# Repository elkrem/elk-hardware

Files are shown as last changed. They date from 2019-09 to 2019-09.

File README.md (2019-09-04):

# Elk Board Schematics and Board files #

## Overview ##

This repository contains the schematics and board files for [Elk](https://www.kickstarter.com/projects/233173198/elk-the-dev-board-for-the-decentralized-world) board.

## Status ##

The Elk board project has been [cancelled](https://www.kickstarter.com/projects/233173198/elk-the-dev-board-for-the-decentralized-world/posts/2613884), thus the repo is unmaintained and provided for reference only in the hope it will useful.

There board in the [Kickstarter Video](https://www.kickstarter.com/projects/233173198/elk-the-dev-board-for-the-decentralized-world) is available in this [tag](https://github.com/elkrem/elk-hardware/releases/tag/v1). Other commits has been added after that.

## License and Copyright ##



These files are free; you can redistribute them and/or modify them under the terms of the Creative Commons Attribution-ShareAlike 4.0 International License only, as published by the Creative Commons organization.

These files are distributed in the hope that they will be useful, but WITHOUT ANY WARRANTY; without even the implied warranty of MERCHANTABILITY or FITNESS FOR A PARTICULAR PURPOSE.  See the Creative Commons Attribution-ShareAlike 4.0 International License for more details (a copy is included in the LICENSE file that accompanied these files).

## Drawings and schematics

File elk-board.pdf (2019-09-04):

# MCU Voltage Regulator 3.3V /1A

# USB Connector

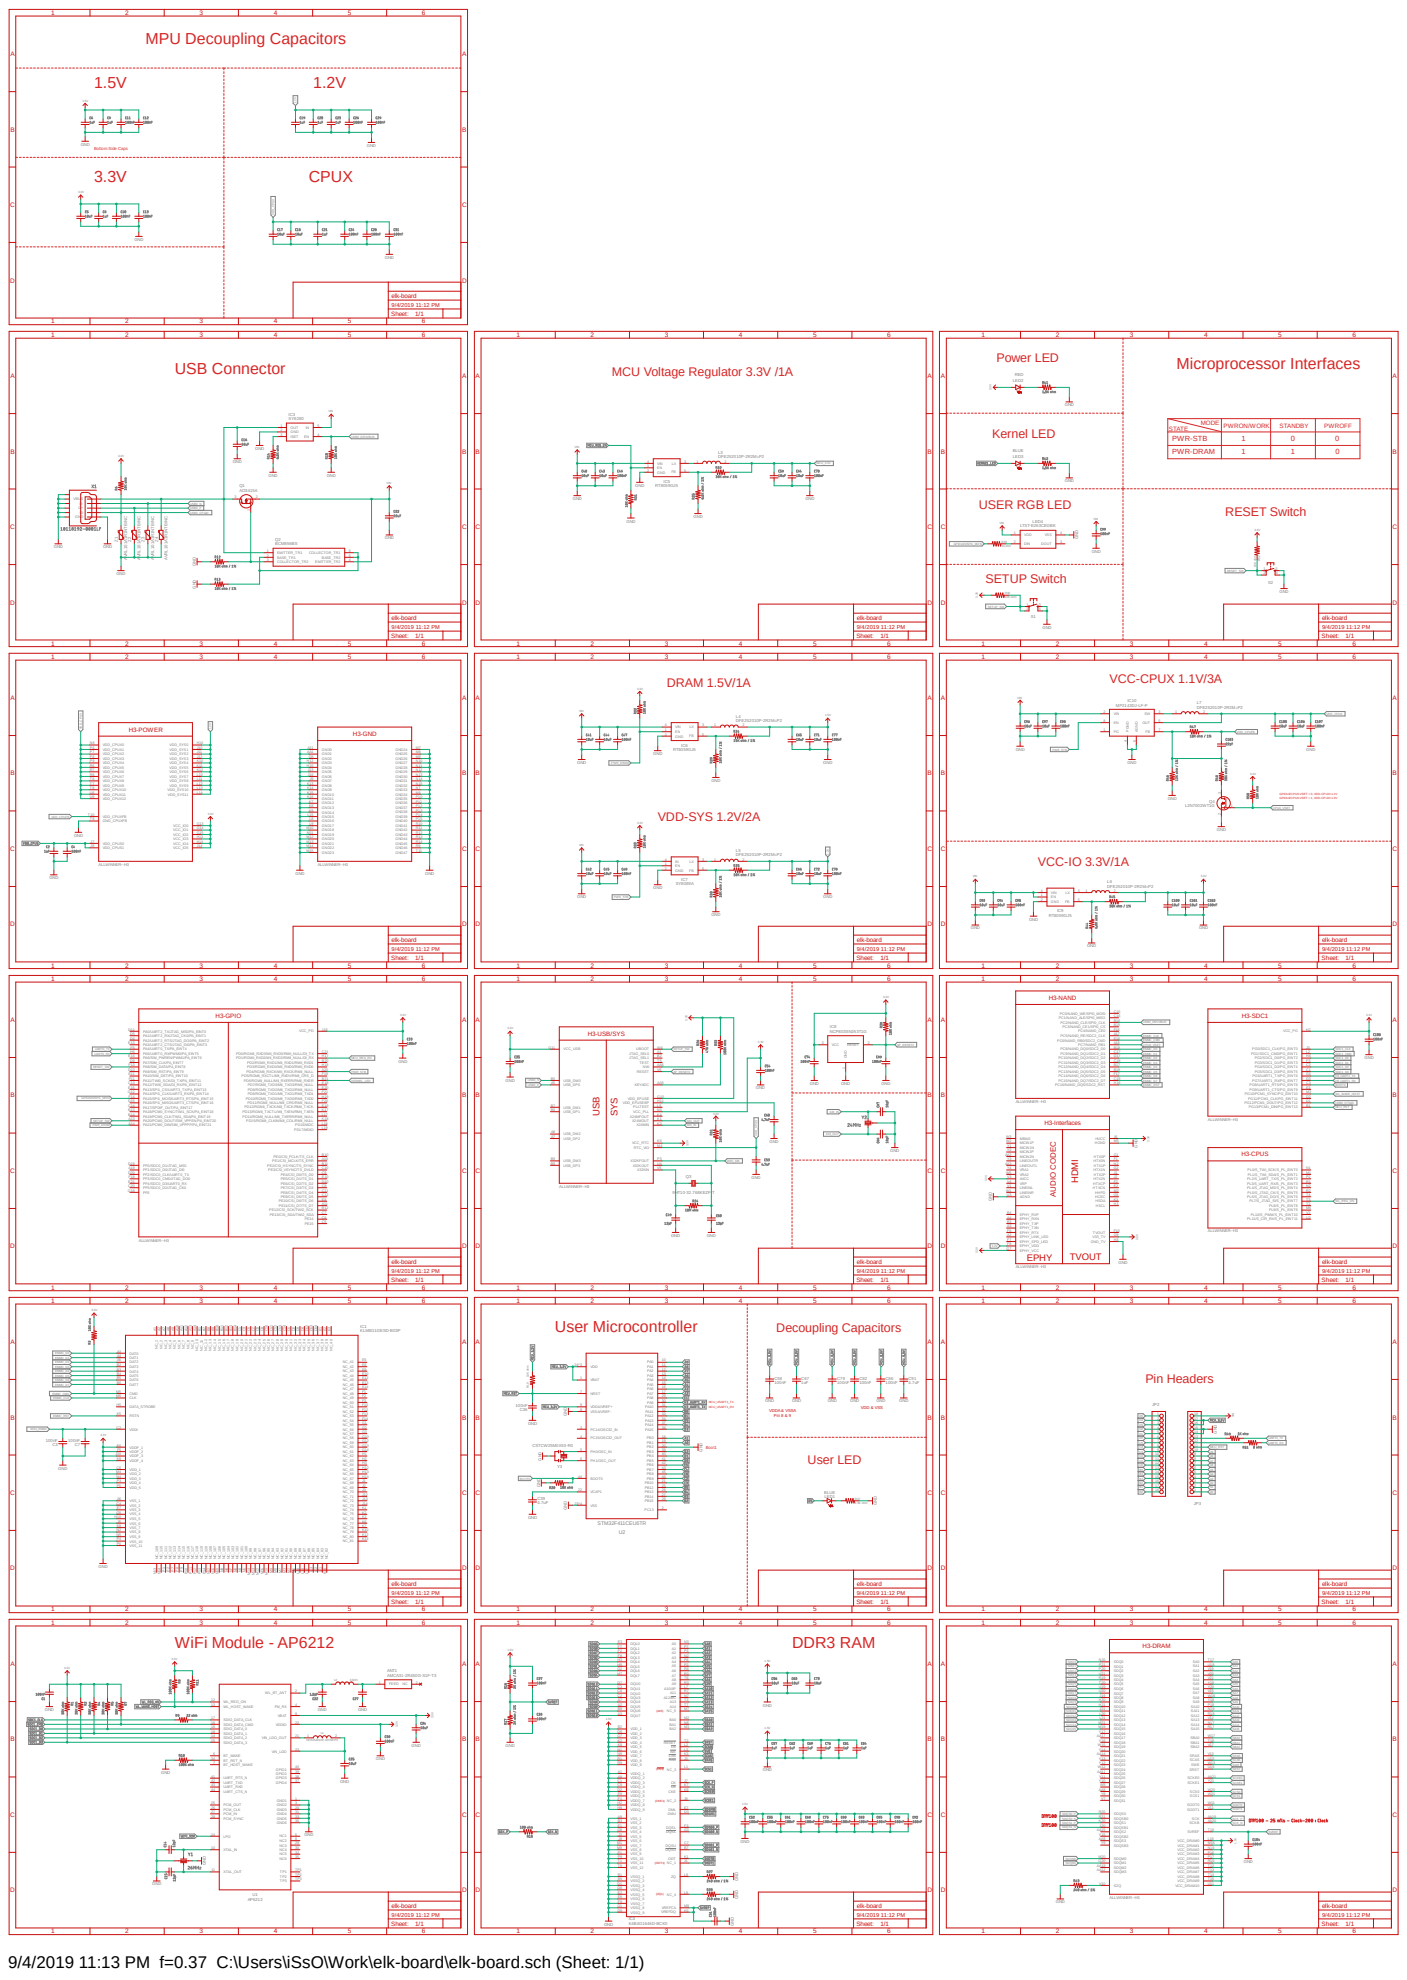
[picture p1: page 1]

MODE | PWRON/WORK | STANDBY | PWROFF 1

PWR-STB | | 0 0
PWR-DRAM | 1 1 | | 0

GPIOL6/CPUX-VSET = 0, VDD-CPUX=1.1V
GPIOL6/CPUX-VSET = 1, VDD-CPUX=1.3V

H3-USB/SYS USB SYS

9/4/2019 11:13 PM f=0.37 C:\Users\iSsO\Work\elk-board\elk-board.sch (Sheet: 1/1)

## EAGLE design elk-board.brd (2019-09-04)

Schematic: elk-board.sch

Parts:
ANT1: AMCA31-2R450G-S1F-T3; ANTC3216X140N
C1, C3, C4, C7, C10, C11, C12, C13, C24, C26, C28, C29, C30, C31, C33, C35, C36, C37, C38, C46, C47, C48, C51, C52, C54, C55, C58, C61, C68, C70, C74, C75, C77, C78, C79, C80, C82, C83, C85, C86, C89, C90, C92, C95, C98, C99, C102, C104, C107, C108: 100nF; 0402
C2, C6, C8, C9, C19, C20, C21, C23, C57, C62, C67, C69, C76, C81, C84: 1uF; 0402
C5, C16, C25, C34, C40, C41, C42, C43, C44, C45, C56, C59, C63, C64, C65, C66, C71, C72, C73, C93, C94, C96, C97, C100, C101: 10uF; 0603
C14, C15, C49, C50: 12pF; 0402
C17, C18, C105, C106: 10uF; TOLBA_0603
C22: 1.5pF; 0402
C27: CAPACITOR-(INCH)-0402; 0402
C32: 22uF; 0603
C39, C53, C60, C91: 4.7uF; 0402
C87, C88: 18pF; 0402
C103: 22pF; 0402
IC1: KLM8G1GESD-B03P; BGA153C50P14X14_1150X1300X80
IC2: ALLWINNER--H3; BGA347C65P21X21_1400X1400X118
IC3: SY6280; SOT95P285X140-5N
IC4: K4B4G1646D-BCK0; BGA96C80P9X16_1000X1330X120
IC5, IC6, IC9: RT8059GJ5; SOT94P280X100-5N
IC7: SY8089A; SOT95P285X140-5N
IC8: NCP803SN263T1G; SOT96P237X111-3N
IC10: MP2143DJ-LF-P; SOT65P280X100-8N
JP2, JP3: PINHD-1X18_2.54-S; 1X18-S
L1: DFE252010P-4R7M=P2; INDC2520X100N
L2: 3.9nH; RESC0402_L
L3, L4, L5, L6, L7: DFE252010P-2R2M=P2; INDC2520X100N
LED1, LED3: BLUE; 0603-LED
LED2: RED; 0603-LED
LED4: LTST-E263CEGBK
Q1: AO3415A; SOT95P280X125-3N
Q2: BCM856BS; SOT65P210X110-6N
Q3: 9HT10-32.768KEZF-T; 3.2X1.5
Q4: L2N7002WT1G; SOT65P220X100-3N
R1, R2, R4, R5, R7: 30K ohm; 0402
R3, R6, R15, R19, R20, R21, R22, R23, R31, R38, R40, R50, R52: 10K ohm; 0402
R8, R10, R11, R33: 100K ohm; 0402
R9: 22 ohm; 0402
R12, R13, R29, R30, R35, R47: 10K ohm / 1%; 0402
R14: 6.8K ohm; 0402
R16, R17: 2K ohm / 1%; 0402
R18: 100 ohm; 0402
R24: 10M ohm; 0402
R25, R44: 6.8K ohm / 1%; 0402
R26: 47K ohm; 0402
R27, R28, R43: 240 ohm / 1%; 0402
R32, R45, R48: 30K ohm / 1%; 0402
R34: 15K ohm / 1%; 0402
R37, R41, R42: 1.5K ohm; 0402
R39: 33 ohm; 0402
R46: 12K ohm / 1%; 0402
R49: 1K ohm; 0402
R51: 0 ohm; 0402
S1, S2: KMR231GLFS; TACTILE_SWITCH_SMD
U1: AP6212
U2: STM32F411CEU6TR; UFQFPN-48
X1: 10118192-0001LF; 10118192-0001LF(MICRO-USB-B-AMPHENOL-FCI)
Y1: 26MHz; 4-SMD-2X1.6MM
Y2: 24MHz; CRYSTAL-SMD-3.2X2.5MM-EPSON-TSX-3225
Y3: CSTCW25M0X53-R0
Z1, Z2, Z3, Z4: AVRL101A1R1NTB/NC; 0402-RES

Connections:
1.2V: C19.1, C20.1, C23.1, C26.1, C29.1, C66.1, C72.1, C78.1, IC2.F8 (EPHY_VDD), IC2.H10 (VDD_SYS0), IC2.J10 (VDD_SYS1), IC2.J11 (VDD_SYS2), IC2.J12 (VDD_SYS3), IC2.K10 (VDD_SYS4), IC2.K11 (VDD_SYS5), IC2.K12 (VDD_SYS6), IC2.L10 (VDD_SYS7), IC2.L11 (VDD_SYS8), IC2.L12 (VDD_SYS9), IC2.L13 (VDD_SYS10), IC2.L14 (VDD_SYS11), L5.2, R35.2
1.5V: C6.1, C9.1, C11.1, C12.1, C37.1, C52.1, C55.1, C56.1, C57.1, C61.1, C62.1, C63.1, C65.1, C68.1, C69.1, C71.1, C73.1, C75.1, C76.1, C77.1, C80.1, C81.1, C83.1, C84.1, C85.1, C90.1, C92.1, IC2.L16 (VCC_DRAM0), IC2.M16 (VCC_DRAM1), IC2.N16 (VCC_DRAM2), IC2.P16 (VCC_DRAM3), IC2.P17 (VCC_DRAM4), IC2.R16 (VCC_DRAM5), IC2.T12 (VCC_DRAM6), IC2.T13 (VCC_DRAM7), IC2.T14 (VCC_DRAM8), IC2.T15 (VCC_DRAM9), IC2.U11 (VCC_DRAM10), IC4.A1 (VDDQ_1), IC4.A8 (VDDQ_2), IC4.B2 (VDD_1), IC4.C1 (VDDQ_3), IC4.C9 (VDDQ_4), IC4.D2 (VDDQ_5), IC4.D9 (VDD_2), IC4.E9 (VDDQ_6), IC4.F1 (VDDQ_7), IC4.G7 (VDD_3), IC4.H2 (VDDQ_8), IC4.H9 (VDDQ_9), IC4.K2 (VDD_4), IC4.K8 (VDD_5), IC4.N1 (VDD_6), IC4.N9 (VDD_7), IC4.R1 (VDD_8), IC4.R9 (VDD_9), L4.2, R16.2, R34.2
3.3V: C1.2, C5.1, C8.1, C10.1, C13.1, C30.1, C33.1, C34.1, C35.1, C54.1, C74.1, C100.1, C101.1, C102.1, C108.1, IC1.C6 (VDD_1), IC1.E6 (VDDF_1), IC1.F5 (VDDF_2), IC1.J10 (VDDF_3), IC1.K9 (VDDF_4), IC1.M4 (VDD_2), IC1.N4 (VDD_3), IC1.P3 (VDD_4), IC1.P5 (VDD_5), IC2.G7 (EPHY_VCC), IC2.G9 (V33_TV), IC2.G10 (VDD_EFUSE), IC2.G11 (VCC_USB), IC2.G13 (VCC_IO0), IC2.G14 (VCC_IO1), IC2.G15 (VCC_IO2), IC2.H7 (VCC_PG), IC2.H13 (VCC_IO3), IC2.H14 (VCC_IO4), IC2.J6 (HVCC), IC2.J14 (VCC_IO5), IC2.J15 (VCC_PD), IC2.K6 (VCC_RTC), IC2.N3 (VCC_PLL), IC2.V3 (AVCC), IC8.3 (VCC), L6.2, LED2.A, R1.1, R2.1, R3.2, R4.1, R5.1, R6.2, R7.1, R8.1, R11.1, R22.2, R23.2, R26.1, R31.1, R33.1, R38.1, R40.1, R45.2, R50.2, R52.1, U1.9 (VBAT), U1.22 (VDDIO)
A0: JP3.1, U2.19 (PB1)
A1: JP3.2, U2.18 (PB0)
A2: JP3.3, U2.17 (PA7)
A3: JP3.4, U2.16 (PA6)
A4: JP3.5, U2.15 (PA5)
A5: JP3.6, U2.14 (PA4)
A6: JP3.7, U2.13 (PA3)
A7: JP3.8, U2.12 (PA2)
A8: JP3.9, U2.11 (PA1)
A9: JP3.10, U2.10 (PA0)
AP_RESET#: C89.1, IC2.V6 (RESET), IC8.2 (!RESET), R38.2
B0: JP2.18, U2.32 (PA11)
B1: JP2.17, U2.33 (PA12)
B2: JP2.16, U2.28 (PB15)
B3: JP2.15, U2.27 (PB14)
B4: JP2.14, U2.26 (PB13)
B5: JP2.13, U2.25 (PB12)
BOOT0: IC2.C3 (PG8/UART1_RTS/PG_EINT8), R20.1, U2.44 (BOOT0)
C0: JP2.12, U2.45 (PB8)
C1: JP2.11, U2.29 (PA8)
C2: JP2.10, U2.46 (PB9)
C3: JP2.9, U2.21 (PB10)
C4: JP2.8, U2.43 (PB7)
C5: JP2.7, U2.42 (PB6)
CPUX_VSET: IC2.A16 (PC7/NAND_RB1), Q4.1 (G), R50.1
D0: JP2.6, U2.41 (PB5)
D1: JP2.5, U2.40 (PB4)
D2: JP2.4, U2.39 (PB3)
D3: JP2.3, U2.38 (PA15)
D4: JP2.2, U2.37 (PA14)
D5: JP2.1, LED1.A, U2.34 (PA13)
EMMC_CLK: IC1.M6 (CLK), IC2.A17 (PC5/NAND_RE/SDC2_CLK)
EMMC_CMD: IC1.M5 (CMD), IC2.E16 (PC6/NAND_RB0/SDC2_CMD), R3.1
EMMC_D0: IC1.A3 (DAT0), IC2.B18 (PC8/NAND_DQ0/SDC2_D0)
EMMC_D1: IC1.A4 (DAT1), IC2.C17 (PC9/NAND_DQ1/SDC2_D1)
EMMC_D2: IC1.A5 (DAT2), IC2.D17 (PC10/NAND_DQ2/SDC2_D2)
EMMC_D3: IC1.B2 (DAT3), IC2.C18 (PC11/NAND_DQ3/SDC2_D3)
EMMC_D4: IC1.B3 (DAT4), IC2.B17 (PC12/NAND_DQ4/SDC2_D4)
EMMC_D5: IC1.B4 (DAT5), IC2.B19 (PC13/NAND_DQ5/SDC2_D5)
EMMC_D6: IC1.B5 (DAT6), IC2.F17 (PC14/NAND_DQ6/SDC2_D6)
EMMC_D7: IC1.B6 (DAT7), IC2.C19 (PC15/NAND_DQ7/SDC2_D7)
EMMC_RST: IC1.K5 (RSTN), IC2.H16 (PC16/NAND_DQS/SDC2_RST)
GND: C1.1, C2.2, C3.1, C4.2, C5.2, C6.2, C7.1, C8.2, C9.2, C10.2, C11.2, C12.2, C13.2, C14.1, C15.1, C16.2, C17.2, C18.2, C19.2, C20.2, C21.2, C22.1, C23.2, C24.2, C25.2, C26.2, C27.1, C28.2, C29.2, C30.2, C31.2, C32.2, C33.2, C34.2, C35.2, C36.1, C38.2, C39.2, C40.2, C41.2, C42.2, C43.2, C44.2, C45.2, C46.2, C47.2, C48.2, C49.2, C50.2, C51.2, C52.2, C53.2, C54.2, C55.2, C56.2, C57.2, C58.2, C59.2, C60.2, C61.2, C62.2, C63.2, C64.2, C65.2, C66.2, C67.2, C68.2, C69.2, C70.2, C71.2, C72.2, C73.2, C74.2, C75.2, C76.2, C77.2, C78.2, C79.2, C80.2, C81.2, C82.2, C83.2, C84.2, C85.2, C86.2, C87.1, C88.1, C89.2, C90.2, C91.2, C92.2, C93.2, C94.2, C95.2, C96.2, C97.2, C98.2, C99.2, C100.2, C101.2, C102.2, C104.2, C105.2, C106.2, C107.2, C108.2, IC1.A6 (VSS_1), IC1.C4 (VSS_2), IC1.E7 (VSS_3), IC1.G5 (VSS_4), IC1.H10 (VSS_5), IC1.J5 (VSS_6), IC1.K8 (VSS_7), IC1.N2 (VSS_8), IC1.N5 (VSS_9), IC1.P4 (VSS_10), IC1.P6 (VSS_11), IC2.A21 (GND0), IC2.AA1 (GND1), IC2.G8 (GND2), IC2.H8 (GND_TV), IC2.H12 (GND3), IC2.H15 (GND4), IC2.J9 (GND7), IC2.J13 (GND5), IC2.J16 (GND6), IC2.K7 (GND12), IC2.K8 (GND13), IC2.K9 (GND14), IC2.K13 (GND8), IC2.K14 (GND9), IC2.K15 (GND10), IC2.K16 (GND11), IC2.L8 (GND16), IC2.L9 (GND17), IC2.L15 (GND15), IC2.M5 (HGND), IC2.M7 (GND24), IC2.M8 (GND25), IC2.M9 (GND26), IC2.M10 (GND18), IC2.M11 (GND19), IC2.M12 (GND20), IC2.M13 (GND21), IC2.M14 (GND22), IC2.M15 (GND23), IC2.N7 (GND33), IC2.N9 (GND34), IC2.N10 (GND27), IC2.N11 (GND28), IC2.N12 (GND29), IC2.N13 (GND30), IC2.N14 (GND31), IC2.N15 (GND32), IC2.P10 (GND35), IC2.P11 (GND36), IC2.P12 (GND37), IC2.P13 (GND38), IC2.P14 (GND39), IC2.P15 (GND40), IC2.R9 (GND46), IC2.R10 (GND41), IC2.R11 (GND42), IC2.R12 (GND43), IC2.R13 (GND44), IC2.R14 (GND45), IC2.T9 (GND_CPUXFB), IC2.T11 (GND47), IC2.U3 (AGND), IC3.2 (GND), IC4.A9 (VSS_1), IC4.B1 (VSSQ_1), IC4.B3 (VSS_2), IC4.B9 (VSSQ_2), IC4.D1 (VSSQ_3), IC4.D8 (VSSQ_4), IC4.E1 (VSS_3), IC4.E2 (VSSQ_5), IC4.E8 (VSSQ_6), IC4.F9 (VSSQ_7), IC4.G1 (VSSQ_8), IC4.G8 (VSS_4), IC4.G9 (VSSQ_9), IC4.J2 (VSS_5), IC4.J8 (VSS_6), IC4.M1 (VSS_7), IC4.M9 (VSS_8), IC4.P1 (VSS_9), IC4.P9 (VSS_10), IC4.T1 (VSS_11), IC4.T9 (VSS_12), IC5.2 (GND), IC6.2 (GND), IC7.2 (GND), IC8.1 (GND), IC9.2 (GND), IC10.4 (PGND), IC10.6 (AGND), JP3.14, JP3.15, LED4.4 (VSS), Q4.2 (S), R10.1, R12.1, R13.1, R14.1, R15.1, R17.1, R20.2, R21.2, R25.1, R27.2, R28.2, R29.1, R30.1, R37.2, R41.2, R42.2, R43.1, R44.1, R46.1, S1.3, S1.4, S2.3, S2.4, U1.1 (GND1), U1.3 (GND2), U1.20 (GND3), U1.31 (GND4), U1.33 (GND5), U1.36 (GND6), U2.8 (VSSA/VREF-), U2.20 (PB2), U2.23 (VSS), U2.35 (VSS), U2.47 (VSS), U2.49 (VSS), X1.CGND1 (SGND1), X1.CGND2 (SGND2), X1.CGND3 (SGND3), X1.CGND4 (SGND4), X1.CGND5 (SGND5), X1.CGND6 (SGND6), X1.GND, Y1.2, Y1.4, Y2.2 (3), Y2.4 (3), Y3.GND, Z1.1, Z2.1, Z3.1, Z4.1
GPIOA15/SPI1_MOSI: IC2.F14 (PA15/SPI1_MOSI/UART3_RTS/PA_EINT15), R39.1
H3_UART1_RX: IC2.D3 (PG7/UART1_RX/PG_EINT7), U2.30 (PA9)
H3_UART1_TX: IC2.G4 (PG6/UART1_TX/PG_EINT6), U2.31 (PA10)
KERNEL_LED: IC2.B21 (PD6/RGMII_NULL/MII_RXERR/RMII_RXER), LED3.A
MCU_3.3V: C58.1, C59.1, C64.1, C67.1, C70.1, C79.1, C82.1, C86.1, C91.1, JP3.16, JP3.17, L3.2, R19.1, R32.2, U2.1 (VBAT), U2.9 (VDDA/VREF+), U2.24 (VDD), U2.36 (VDD), U2.48 (VDD)
MCU_REG_EN: IC2.H17 (PD1/RGMII_RXD2/MII_RXD2/RMII_NULL/DI_RX), IC5.1 (EN), R21.1
MCU_RST: C36.2, IC2.B1 (PG13/PCM1_DIN/PG_EINT13), JP3.11, R19.2, U2.7 (NRST)
unnamed: R9.1, U1.17 (SDIO_DATA_CLK)
unnamed: JP3.12, R51.2
unnamed: IC5.3 (LX), L3.1
unnamed: LED1.K, R37.1
unnamed: LED3.K, R42.1
unnamed: IC6.3 (LX), L4.1
unnamed: R10.2, U1.34 (BT_RST_N)
unnamed: IC5.5 (FB), R25.2, R32.1
unnamed: C15.2, U1.11 (XTAL_OUT), Y1.1
unnamed: C14.2, U1.10 (XTAL_IN), Y1.3
unnamed: JP3.13, R49.2
unnamed: ANT1.1 (FEED), C27.2, L2.2
unnamed: LED4.2 (DIN), R39.2
unnamed: C25.1, L1.2, U1.23 (VIN_LDO)
unnamed: U2.5 (PH0/OSC_IN), Y3.IN
unnamed: U2.6 (PH1/OSC_OUT), Y3.OUT
unnamed: L1.1, U1.21 (VIN_LDO_OUT)
unnamed: IC6.5 (FB), R29.2, R34.1
unnamed: IC7.3 (LX), L5.1
unnamed: C22.2, L2.1, U1.2 (WL_BT_ANT)
unnamed: LED2.K, R41.1
unnamed: C39.1, U2.22 (VCAP1)
unnamed: IC4.L8 (ZQ), R27.1
unnamed: C16.1, IC3.1 (OUT), Q1.3 (D), Q2.1 (EMITTER_TR1), X1.VBUS, Z4.2
unnamed: IC7.5 (FB), R30.2, R35.1
unnamed: C49.1, IC2.V5 (X32KIN), Q3.1, R24.2
unnamed: IC10.3 (SW), L7.1
unnamed: C103.2, IC10.7 (FB), R46.2, R47.1, R48.2
unnamed: IC3.3 (ISET), R14.2
unnamed: IC9.3 (LX), L6.1
unnamed: IC2.V10 (SZQ), R43.2
unnamed: IC9.5 (FB), R44.2, R45.1
unnamed: Q4.3 (D), R48.1
unnamed: Q1.1 (G), Q2.3 (COLLECTOR_TR2), R12.2
unnamed: Q2.2 (BASE_TR1), Q2.5 (BASE_TR2), Q2.6 (COLLECTOR_TR1), R13.2
unnamed: C50.1, IC2.U4 (X32KOUT), Q3.2, R24.1
unnamed: C60.1, IC2.H11 (VDD_EFUSEBP)
unnamed: IC2.AA6 (NMI), R26.2
unnamed: IC2.AA5 (KEYADC), R33.2
unnamed: IC4.L9 (NC_4), R28.1
PWR_DRAM: IC2.A14 (PA21/PCM0_DIN/SIM_VPPPP/PA_EINT21), IC6.1 (EN), R22.1
PWR_STB: IC2.A20 (PD4/RGMII_RXCK/MII_RXCK/RMII_NULL), IC7.1 (EN), IC10.8 (EN), R23.1
RESET_SW: IC2.F13 (PA8/SIM_DATA/PA_EINT8), R52.2, S2.1, S2.2
SA0: IC2.T17 (SA0), IC4.N3 (A0)
SA1: IC2.U18 (SA1), IC4.P7 (A1)
SA2: IC2.V19 (SA2), IC4.P3 (A2)
SA3: IC2.V20 (SA3), IC4.N2 (A3)
SA4: IC2.V21 (SA4), IC4.P8 (A4)
SA5: IC2.Y19 (SA5), IC4.P2 (A5)
SA6: IC2.Y20 (SA6), IC4.R8 (A6)
SA7: IC2.V15 (SA7), IC4.R2 (A7)
SA8: IC2.W18 (SA8), IC4.T8 (A8)
SA9: IC2.Y18 (SA9), IC4.R3 (A9)
SA10: IC2.P19 (SA10), IC4.L7 (A10/AP)
SA11: IC2.N19 (SA11), IC4.R7 (A11)
SA12: IC2.R18 (SA12), IC4.N7 (A12/!BC)
SA13: IC2.V12 (SA13), IC4.T3 (A13)
SA14: IC2.N17 (SA14), IC4.T7 (A14)
SA15: IC2.R17 (SA15), IC4.M7 (NC_5)
SBA0: IC2.W17 (SBA0), IC4.M2 (BA0)
SBA1: IC2.T18 (SBA1), IC4.N8 (BA1)
SBA2: IC2.V17 (SBA2), IC4.M3 (BA2)
SCAS: IC2.U15 (SCAS), IC4.K3 (!CAS)
SCKE0: IC2.AA21 (SCKE0), IC4.K9 (CKE)
SCKE1: IC2.Y21 (SCKE1), IC4.J9 (NC_2)
SCK_N: IC2.AA20 (SCKB), IC4.K7 (!CK), R18.1
SCK_P: IC2.AA19 (SCK), IC4.J7 (CK), R18.2
SCS0: IC2.W20 (SCS0), IC4.L2 (!CS)
SCS1: IC2.W21 (SCS1), IC4.L1 (NC_3)
SDC1_CLK: IC2.J3 (PG0/SDC1_CLK/PG_EINT0), R9.2
SDC1_CMD: IC2.L2 (PG1/SDC1_CMD/PG_EINT1), R7.2, U1.16 (SDIO_DATA_CMD)
SDC1_D0: IC2.H4 (PG2/SDC1_D0/PG_EINT2), R5.2, U1.18 (SDIO_DATA_0)
SDC1_D1: IC2.F3 (PG3/SDC1_D1/PG_EINT3), R4.2, U1.19 (SDIO_DATA_1)
SDC1_D2: IC2.C2 (PG4/SDC1_D2/PG_EINT4), R2.2, U1.14 (SDIO_DATA_2)
SDC1_D3: IC2.C1 (PG5/SDC1_D3/PG_EINT5), R1.2, U1.15 (SDIO_DATA_3)
SDQ0: IC2.N20 (SDQ0), IC4.F7 (DQL1)
SDQ1: IC2.P21 (SDQ1), IC4.H8 (DQL5)
SDQ2: IC2.P20 (SDQ2), IC4.F8 (DQL3)
SDQ3: IC2.U21 (SDQ3), IC4.H3 (DQL4)
SDQ4: IC2.R19 (SDQ4), IC4.H7 (DQL7)
SDQ5: IC2.T20 (SDQ5), IC4.E3 (DQL0)
SDQ6: IC2.U19 (SDQ6), IC4.G2 (DQL6)
SDQ7: IC2.U20 (SDQ7), IC4.F2 (DQL2)
SDQ8: IC2.J19 (SDQ8), IC4.A7 (DQU4)
SDQ9: IC2.H20 (SDQ9), IC4.A2 (DQU5)
SDQ10: IC2.H21 (SDQ10), IC4.A3 (DQU7)
SDQ11: IC2.J21 (SDQ11), IC4.B8 (DQU6)
SDQ12: IC2.L20 (SDQ12), IC4.C8 (DQU2)
SDQ13: IC2.L21 (SDQ13), IC4.D7 (DQU0)
SDQ14: IC2.M21 (SDQ14), IC4.C3 (DQU1)
SDQ15: IC2.M19 (SDQ15), IC4.C2 (DQU3)
SDQM0: IC2.M20 (SDQM0), IC4.E7 (DML)
SDQM1: IC2.G20 (SDQM1), IC4.D3 (DMU)
SDQS0_N: IC2.R21 (SDQSB0), IC4.G3 (!DQSL)
SDQS0_P: IC2.R20 (SDQS0), IC4.F3 (DQSL)
SDQS1_N: IC2.J20 (SDQSB1), IC4.B7 (!DQSU)
SDQS1_P: IC2.K20 (SDQS1), IC4.C7 (DQSU)
SETUP_SW: IC2.A13 (PA20/PCM0_DOUT/SIM_VPPEN/PA_EINT20), IC2.W6 (UBOOT), R40.2, S1.1, S1.2
SODT0: IC2.W11 (SODT0), IC4.K1 (ODT)
SODT1: IC2.V11 (SODT1), IC4.J1 (NC_1)
SRAS: IC2.V13 (SRAS), IC4.J3 (!RAS)
SRST: IC2.U16 (SRST), IC4.T2 (!RESET)
SVREF: C37.2, C38.1, C51.1, C104.1, IC2.T16 (SVREF), IC4.H1 (VREFDQ), IC4.M8 (VREFCA), R16.1, R17.2
SWE: IC2.W13 (SWE), IC4.L3 (!WE)
UART0_RX: IC2.H6 (PA5/UART0_RX/PWM0/PA_EINT5), R51.1
UART0_TX: IC2.F5 (PA4/UART0_TX/PA_EINT4), R49.1
USB0_DRVVBUS: IC2.B16 (PC2/NAND_CLE/SPI0_CLK), IC3.4 (EN), R15.2
USB0_N: IC2.B5 (USB_DM0), X1.D-, Z3.2
USB0_OTGID: IC2.D1 (PG12/PCM1_DOUT/PG_EINT12), R6.1, X1.ID, Z1.2
USB0_P: IC2.A5 (USB_DP0), X1.D+, Z2.2
VDDI_EMMC: C3.2, C7.2, IC1.C2 (VDDI)
VDD_CPUFB: C103.1, IC2.T10 (VDD_CPUXFB), R47.2
VDD_CPUS: C2.1, C4.1, C53.1, IC2.J7 (VDD_CPUS0), IC2.J8 (VDD_CPUS1), IC2.M4 (RTC_VIO)
VDD_CPUX: C17.1, C18.1, C21.1, C24.1, C28.1, C31.1, C105.1, C106.1, C107.1, IC2.N8 (VDD_CPUX0), IC2.P6 (VDD_CPUX1), IC2.P7 (VDD_CPUX2), IC2.P8 (VDD_CPUX3), IC2.P9 (VDD_CPUX4), IC2.R6 (VDD_CPUX5), IC2.R7 (VDD_CPUX6), IC2.R8 (VDD_CPUX7), IC2.T6 (VDD_CPUX8), IC2.T7 (VDD_CPUX9), IC2.T8 (VDD_CPUX10), IC2.U6 (VDD_CPUX11), IC2.U9 (VDD_CPUX12), IC10.5 (OUT), L7.2
VIN: C32.1, C40.1, C41.1, C42.1, C43.1, C44.1, C45.1, C46.1, C47.1, C48.1, C93.1, C94.1, C95.1, C96.1, C97.1, C98.1, C99.1, IC3.5 (IN), IC5.4 (VIN), IC6.4 (VIN), IC7.4 (IN), IC9.1 (EN), IC9.4 (VIN), IC10.2 (VIN), JP3.18, LED4.1 (VDD), Q1.2 (S), Q2.4 (EMITTER_TR2)
WIFI_32K: IC2.P3 (X32KFOUT), R31.2, U1.24 (LPO)
WL_REG_ON: IC2.T3 (PL7/S_JTAG_SI/S_PL_EINT7), R11.2, U1.12 (WL_REG_ON)
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

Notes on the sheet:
WiFi Module - AP6212
DDR3 RAM
MCU Voltage Regulator 3.3V /1A
Decoupling Capacitors
VDDA & VSSA Pin 8 & 9
VDD & VSS
User LED
User Microcontroller
Pin Headers
USB Connector
DRAM 1.5V/1A
VDD-SYS 1.2V/2A
VCC-CPUX 1.1V/3A
VCC-IO 3.3V/1A
Microprocessor Interfaces
MCU_USART1_TX
MCU_USART1_RX
USER RGB LED
SETUP Switch
Kernel LED
Power LED
PWR-STB
PWR-DRAM
PWRON/WORK
STANDBY
PWROFF
MODE
STATE
RESET Switch
Boot1
MPU Decoupling Capacitors
GPIOL6/CPUX-VSET = 0, VDD-CPUX=1.1V GPIOL6/CPUX-VSET = 1, VDD-CPUX=1.3V
Bottom Side Caps
Diff100
Diff100 - 25 mils - Clock-200 : Clock
CPUX
3.3V
1.2V
1.5V

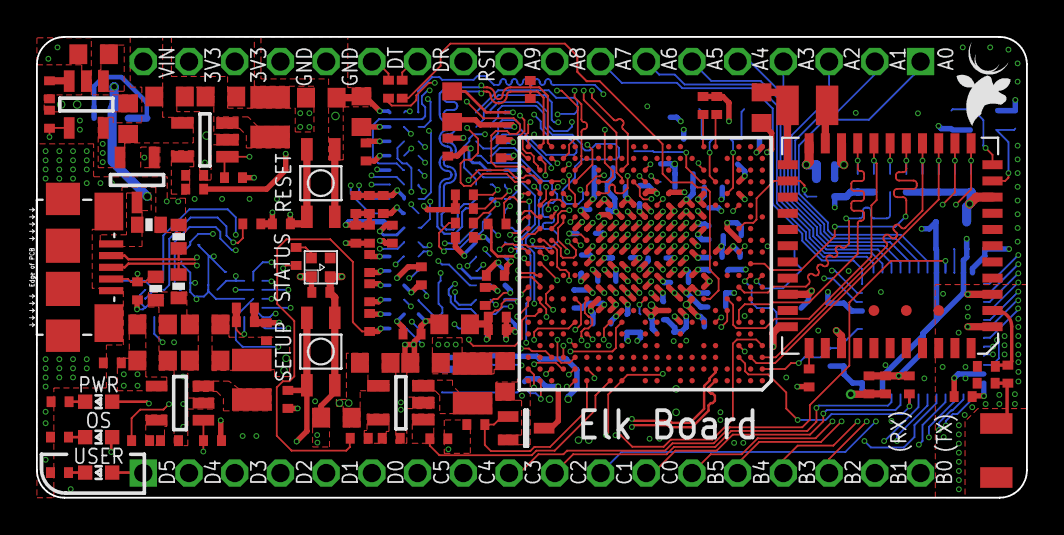
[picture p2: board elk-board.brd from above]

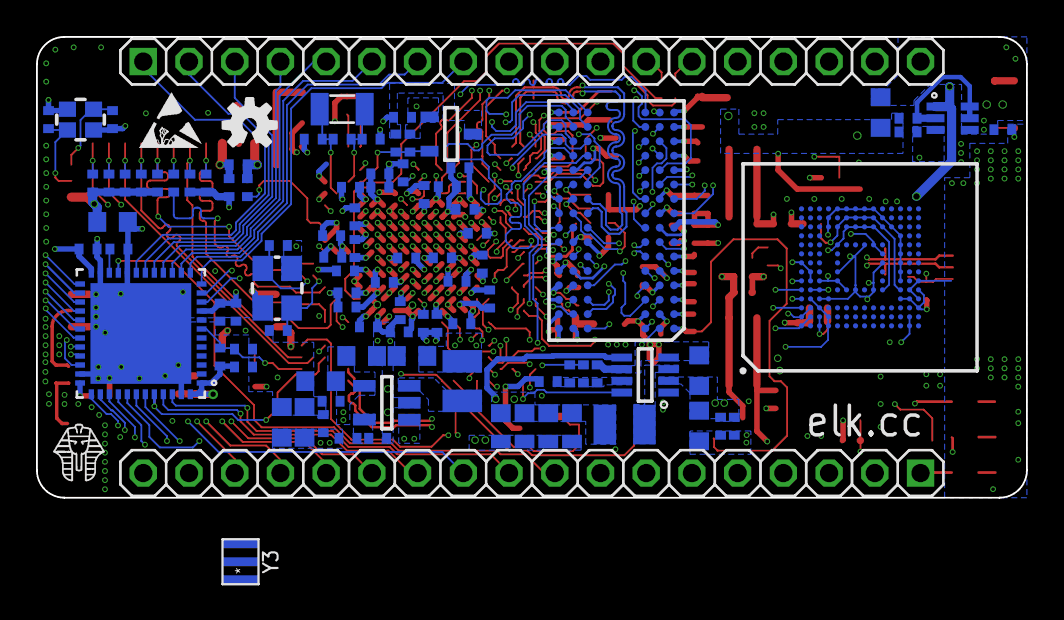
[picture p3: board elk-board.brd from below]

Board: 8 copper layers, 55.0 x 25.6 mm, 200 parts (98 on the bottom side), 173 nets.

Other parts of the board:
U$1: OSHW-LOGO-S

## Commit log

2019-07-08 Initial commit
    1st iteration (H3) sent to China on June, 12th, 2019
    [elk-board.brd, elk-board.sch]
2019-09-04 Added pdf schematics
2019-09-04 Added emmc chip and integrated antenna
    [elk-board.brd, elk-board.sch]
2019-09-04 Finished emmc and antenna (WIP)
    [elk-board.brd, elk-board.sch]
2019-09-04 Finished eMMC Data Lines legth matching (CMD is not included)
    [elk-board.brd, elk-board.sch]
2019-09-04 Modified the GND & PWR Planes around the Antenna
    [elk-board.brd]
2019-09-04 Moved the Antenna a little bit
    [elk-board.brd]
2019-09-04 Added and Modified GND vias and increased eMMC CLK length and it's clearance with nearby traces
    [elk-board.brd]
2019-09-04 Added Some GND vias and moved USB_DRVVBUS via position
    [elk-board.brd]
2019-09-04 Changed the RAM part Number in the schematic and modified the Wifi module label
    [elk-board.brd, elk-board.sch]
2019-09-04 Modified DR & DT positions (a Mistake from 1st Iteration)
    [elk-board.brd]
2019-09-04 Decrease LEDs brightness + MCU_REG_ON (Pull Down)
    [elk-board.brd, elk-board.sch]
2019-09-04 CONNECT UBOOT WITH SETUP Button
    [elk-board.brd, elk-board.sch]
2019-09-04 Did UBOOT Push Button layout
    [elk-board.brd]
2019-09-04 Added TX & RX Silkscreen
    [elk-board.brd]
2019-09-04 Added External Oscillator to MCU Schematics
    [elk-board.brd, elk-board.sch]
2019-09-04 Modified USB Diff Pair Impedence and Length Matching
    [elk-board.brd, elk-board.sch]
2019-09-04 90ohm Impedence Control Enhancment
    USB Differenctial Pair
    [elk-board.brd, elk-board.sch]
2019-09-04 RAM Clock Impedance Control
    [elk-board.brd, elk-board.sch]
2019-09-04 Added schematics pdf

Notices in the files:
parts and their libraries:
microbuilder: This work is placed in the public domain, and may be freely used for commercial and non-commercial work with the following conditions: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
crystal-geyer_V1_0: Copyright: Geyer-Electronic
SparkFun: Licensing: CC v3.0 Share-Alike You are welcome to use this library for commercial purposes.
